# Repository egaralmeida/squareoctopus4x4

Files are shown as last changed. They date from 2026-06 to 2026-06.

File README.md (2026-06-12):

# 4x4 LED Matrix — by @squareoctopus

Wi-Fi controlled 4x4 WS2812B LED matrix running on an ESP32, exposing a simple HTTP JSON API for pixels, effects, and frame sequences.

https://youtube.com/shorts/MrOqMmSNaX8

## Hardware

- **Board:** ESP32-C3 Super Mini (select **ESP32C3 Dev Module** in the boards list) — this is the board the default case is designed for
- **LEDs:** WS2812B strip/matrix, 17 LEDs total, data on **GPIO 4**
- **Layout:** serpentine (zig-zag) rows, 4 wide × 4 tall

### Why LED 0 is ignored

The strip has **17** LEDs but only **16** are visible. LED 0 is a *sacrificial level shifter*: WS2812B data nominally needs 5 V logic, but the ESP32 outputs 3.3 V. The first LED sits close to the ESP32 and (powered appropriately) still reads the 3.3 V signal, then **regenerates the data line at full logic level** for the rest of the strip. It is kept permanently black and is invisible to the API — coordinates `(0,0)`–`(3,3)` map to physical LEDs 1–16.

## Deploying

### Requirements

- [Arduino IDE](https://www.arduino.cc/en/software) or [arduino-cli](https://arduino.github.io/arduino-cli/)
- **ESP32 board support** (Boards Manager: `esp32` by Espressif)
- Libraries (Library Manager):
  - **FastLED**
  - **ArduinoJson**
  - (`WiFi`, `WebServer`, `DNSServer`, `ESPmDNS`, `Preferences` ship with the ESP32 core)

### Flash

Arduino IDE: open `4x4.ino`, select your ESP32 board and port, Upload.

arduino-cli:

```sh
arduino-cli compile --fqbn esp32:esp32:esp32c3 .
arduino-cli upload --fqbn esp32:esp32:esp32c3 -p COM5 .   # adjust port
```

## First-time Wi-Fi setup

The device stores Wi-Fi credentials in flash (NVS). On boot:

1. If credentials are stored, it tries to connect for ~20 seconds.
2. If there are no credentials, or the connection fails, it starts its own access point.

To provision:

1. Connect your phone/laptop to the open Wi-Fi network **`squareoctopus-4x4`**.
2. A captive portal should open automatically (otherwise browse to `http://192.168.4.1`).
3. Pick your network from the list (or type the SSID), enter the password, hit **Connect**.
4. The device reboots and joins your network.

### Finding the device

- **mDNS:** the device is reachable at **`http://squareoctopus-4x4.local`** — no IP needed (works out of the box on macOS, iOS, Android and most Linux distros; on Windows it works on recent versions or with Bonjour installed).
- **Router:** it appears as `squareoctopus-4x4` in your router's DHCP client list.
- **Serial monitor** (115200 baud): the IP is printed on boot.

### Status bar (middle row of the matrix)

| Display | Meaning |
|---|---|
| 🔵 Blue sweeping bar | Searching for / connecting to Wi-Fi |
| 🔴 Red blinking bar | Stored network not found / connection failed |
| 🟠 Orange pulsing bar | Setup (AP) mode — connect to `squareoctopus-4x4` |

The status bar follows the configured `rotation`.

To re-provision (e.g. new router), `POST /wifi/reset` — or just take the device out of range and it will fall back to AP mode after the timeout.

## API reference

All endpoints accept/return JSON. Base URL: `http://squareoctopus-4x4.local` (or `http://<device-ip>`).

Coordinates: `x` = column (0–3, left→right), `y` = row (0–3, top→bottom), at rotation 0. The `rotation` setting rotates the whole logical coordinate space.

Every successful call returns the current device state:

```json
{
  "ok": true,
  "power": true,
  "brightness": 96,
  "rotation": 0,
  "mode": "idle",
  "effect":   { "running": false, "name": "none", "durationMs": 1000, "repeat": 1, "cyclesCompleted": 0 },
  "sequence": { "loaded": false, "running": false, "frameCount": 0, "currentFrame": 0, "repeat": 1, "cyclesCompleted": 0 }
}
```

Errors return `{"ok": false, "error": "<message>"}` with an HTTP 4xx code.

### `GET /state`

Returns the state object above.

### `POST /state`

Set global options. All fields optional; any combination works.

```json
{
  "power": true,
  "brightness": 128,
  "rotation": 90,
  "stop": true,
  "clear": true
}
```

| Field | Type | Notes |
|---|---|---|
| `power` | bool | `false` stops playback and blanks the matrix |
| `brightness` | int 0–255 | Global brightness |
| `rotation` | int | One of `0`, `90`, `180`, `270` (degrees, clockwise). **Persisted across reboots.** |
| `stop` | bool | Stop any running effect/sequence, keep pixels |
| `clear` | bool | Blank the matrix |

### `POST /pixels`

Set individual pixels (manual mode). Stops any running playback.

```json
{
  "clearFirst": true,
  "show": true,
  "pixels": [
    { "x": 0, "y": 0, "r": 255, "g": 0, "b": 0 },
    { "x": 3, "y": 3, "r": 0, "g": 0, "b": 255 }
  ]
}
```

| Field | Type | Default | Notes |
|---|---|---|---|
| `pixels` | array | required | Each needs `x`, `y`, `r`, `g`, `b` |
| `clearFirst` | bool | `false` | Blank before applying |
| `show` | bool | `true` | `false` buffers without displaying |

### `POST /effect`

Run a built-in effect.

```json
{ "name": "plasma", "durationMs": 5000, "repeat": 0 }
```

| Field | Type | Default | Notes |
|---|---|---|---|
| `name` | string | required | One of `rainbowFade`, `breatheWhite`, `cometTrail`, `plasma`, `colorWipeRows` |
| `durationMs` | int | `5000` | Duration of one cycle |
| `repeat` | int | `1` | Number of cycles; `0` = run forever |

### `POST /sequence`

Upload and play a frame-by-frame animation. Limits: **64 frames**, **16 pixels per frame**.

```json
{
  "repeat": 0,
  "frames": [
    {
      "durationMs": 200,
      "clearFirst": true,
      "clearAfter": false,
      "pixels": [ { "x": 1, "y": 1, "r": 0, "g": 255, "b": 0 } ]
    },
    {
      "durationMs": 200,
      "pixels": [ { "x": 2, "y": 2, "r": 0, "g": 255, "b": 0 } ]
    }
  ]
}
```

| Frame field | Type | Default | Notes |
|---|---|---|---|
| `durationMs` | int | `100` | How long the frame stays on screen |
| `clearFirst` | bool | `true` | Blank before drawing the frame |
| `clearAfter` | bool | `false` | Blank after the frame's duration |
| `pixels` | array | required | Same pixel format as `/pixels` |

`repeat` (top level, default `1`): full sequence loops; `0` = endless.

### `POST /wifi/reset`

Clears the stored Wi-Fi credentials and reboots into setup (AP) mode. No body required.

```sh
curl -X POST http://squareoctopus-4x4.local/wifi/reset
```

---

made with care by **@squareoctopus**

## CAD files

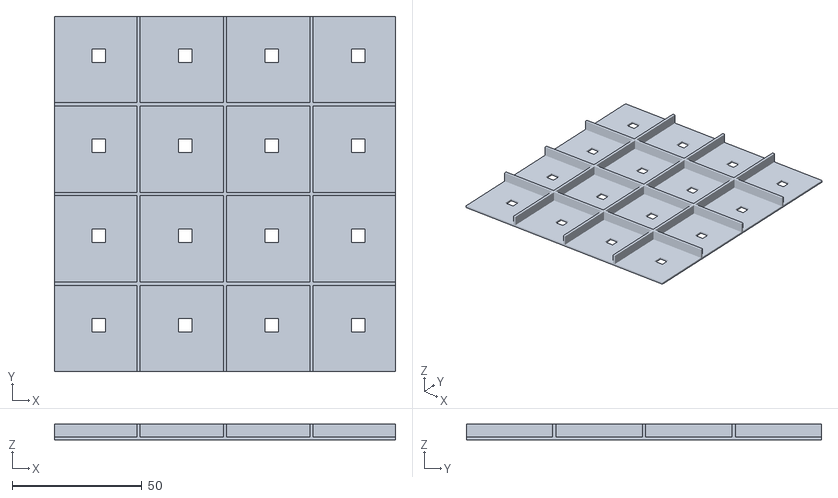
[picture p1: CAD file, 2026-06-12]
LED_support.stl
131.5 x 136.7 x 6.00

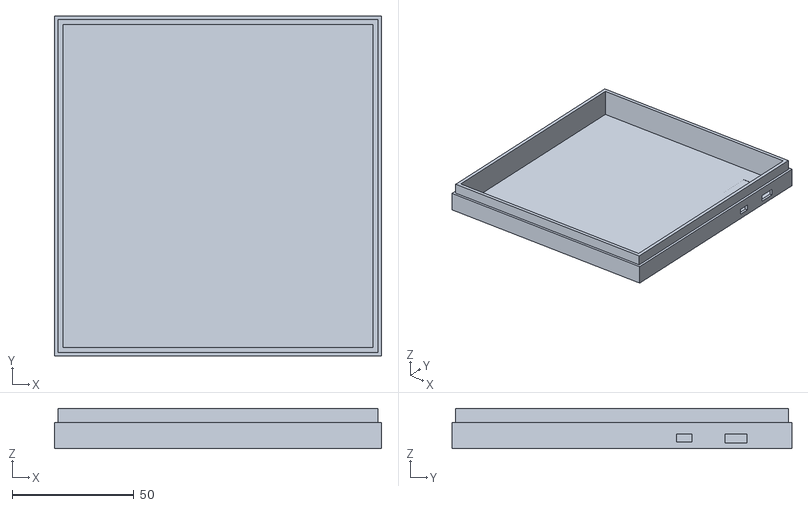
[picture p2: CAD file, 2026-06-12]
back_lid.stl
134.5 x 139.7 x 16.5

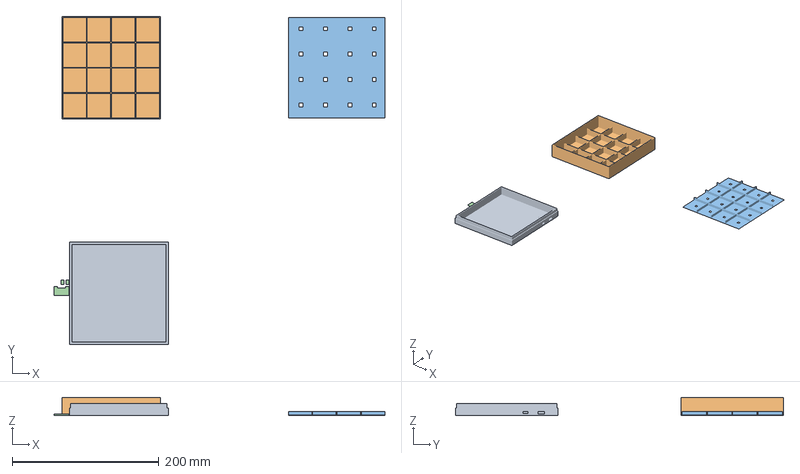
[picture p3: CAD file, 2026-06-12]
squareoctopus4x4.3mf
450.8 x 446.9 x 25.0 mm
back_lid.stl
front.stl
LED_support.stl
esp32_clamps.stl

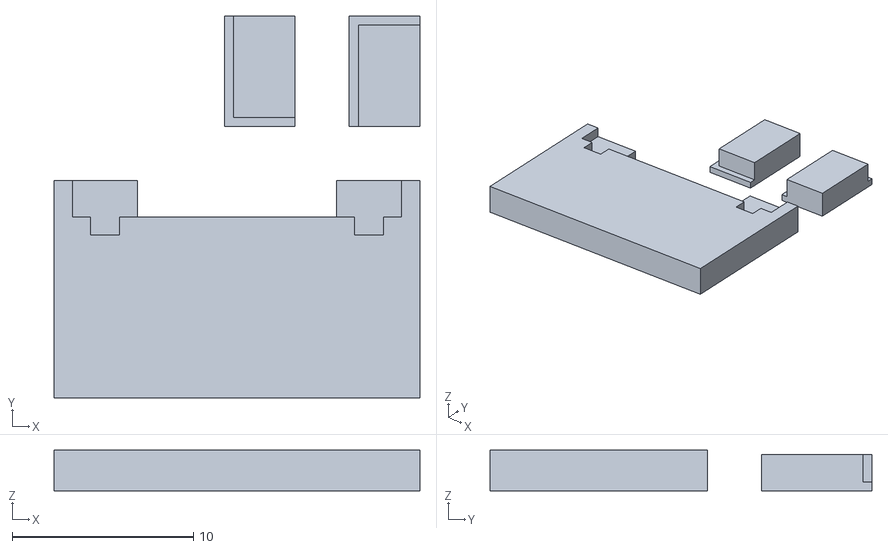
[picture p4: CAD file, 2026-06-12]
esp32_clamps.stl
20.2 x 21.1 x 2.25

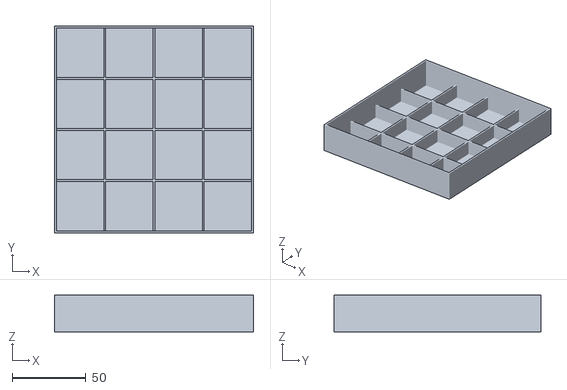
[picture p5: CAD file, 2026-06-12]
front.stl
134.5 x 139.7 x 25.0

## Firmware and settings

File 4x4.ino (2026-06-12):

#include <WiFi.h>
#include <WebServer.h>
#include <DNSServer.h>
#include <ESPmDNS.h>
#include <Preferences.h>
#include <ArduinoJson.h>
#include <FastLED.h>

// ============================
// Wi-Fi provisioning
// ============================
#define AP_SSID            "squareoctopus-4x4"
#define HOSTNAME           "squareoctopus-4x4"
#define WIFI_CONNECT_TIMEOUT_MS 20000
#define NVS_NAMESPACE      "4x4"

Preferences prefs;
DNSServer dnsServer;
bool apMode = false;

// ============================
// LED configuration
// ============================
#define DATA_PIN     4
#define WIDTH        4
#define HEIGHT       4
#define VISIBLE_LEDS (WIDTH * HEIGHT)
#define NUM_LEDS     (VISIBLE_LEDS + 1)   // LED 0 is intentionally ignored
#define LED_TYPE     WS2812B
#define COLOR_ORDER  GRB
#define DEFAULT_BRIGHTNESS 96

CRGB leds[NUM_LEDS];

// ============================
// Server
// ============================
WebServer server(80);

// ============================
// Limits for uploaded sequences
// ============================
static const uint8_t MAX_SEQUENCE_FRAMES = 64;
static const uint8_t MAX_PIXELS_PER_FRAME = 16;

// ============================
// Types
// ============================
enum Mode : uint8_t {
  MODE_OFF = 0,
  MODE_IDLE,
  MODE_MANUAL,
  MODE_EFFECT,
  MODE_SEQUENCE
};

enum EffectType : uint8_t {
  EFFECT_NONE = 0,
  EFFECT_RAINBOW_FADE,
  EFFECT_BREATHE_WHITE,
  EFFECT_COMET_TRAIL,
  EFFECT_PLASMA,
  EFFECT_COLOR_WIPE_ROWS
};

struct PixelUpdate {
  uint8_t x;
  uint8_t y;
  uint8_t r;
  uint8_t g;
  uint8_t b;
};

struct SequenceFrame {
  uint16_t durationMs = 100;
  bool clearFirst = true;
  bool clearAfter = false;
  uint8_t pixelCount = 0;
  PixelUpdate pixels[MAX_PIXELS_PER_FRAME];
};

struct SequenceState {
  bool loaded = false;
  bool running = false;
  uint8_t frameCount = 0;
  uint8_t currentFrame = 0;
  uint32_t repeat = 1;          // 0 = endless
  uint32_t cyclesCompleted = 0;
  uint32_t frameStartedAt = 0;
  SequenceFrame frames[MAX_SEQUENCE_FRAMES];
};

struct EffectState {
  EffectType type = EFFECT_NONE;
  bool running = false;
  uint16_t durationMs = 1000;   // one cycle duration
  uint32_t repeat = 1;          // 0 = endless
  uint32_t cyclesCompleted = 0;
  uint32_t cycleStartedAt = 0;
  uint8_t hue = 0;              // used by comet trail
};

struct DeviceState {
  Mode mode = MODE_IDLE;
  bool power = true;
  uint8_t brightness = DEFAULT_BRIGHTNESS;
  uint16_t rotation = 0; // 0, 90, 180, 270 degrees
} deviceState;

SequenceState sequenceState;
EffectState effectState;

// Used by manual mode / pixels endpoint
bool dirtyShow = false;

// ============================
// Forward declarations
// ============================
uint16_t XY(uint8_t x, uint8_t y);
void showNow();
void clearMatrix(bool show);
void stopAllPlayback(bool keepPixels);
void startEffect(EffectType type, uint16_t durationMs, uint32_t repeat);
void startSequence(uint32_t repeat);
void tickPlayback();
void tickEffect(uint32_t now);
void tickSequence(uint32_t now);
void renderEffectFrame(EffectType type, uint32_t elapsedInCycle);
void handleNotFound();
void handleGetState();
void handlePostState();
void handlePostPixels();
void handlePostEffect();
void handlePostSequence();
bool parseJsonBody(JsonDocument& doc);
void sendJsonError(int code, const char* message);
void sendJsonOk(const String& payload);
const char* modeName(Mode mode);
const char* effectName(EffectType effect);
EffectType parseEffectName(const char* name);
void handlePostWifiReset();
void drawStatusBar(uint8_t progress, CRGB color);
void showNoWifiFeedback();
void tickAPModeFeedback();
bool connectToWiFi();
void startAPMode();
void startApiServer();
void handlePortalRoot();
void handlePortalSave();
void handlePortalRedirect();

// ============================
// XY mapper
// Visible matrix maps to LED 1..16
// LED 0 is ignored on purpose
// Applies the configured rotation before the serpentine mapping
// ============================
uint16_t XY(uint8_t x, uint8_t y) {
  if (x >= WIDTH || y >= HEIGHT) return 0;

  uint8_t rx = x, ry = y;
  switch (deviceState.rotation) {
    case 90:
      rx = HEIGHT - 1 - y;
      ry = x;
      break;
    case 180:
      rx = WIDTH - 1 - x;
      ry = HEIGHT - 1 - y;
      break;
    case 270:
      rx = y;
      ry = WIDTH - 1 - x;
      break;
    default:
      break;
  }
  x = rx;
  y = ry;

  uint16_t physicalIndex;
  if ((y % 2) == 0) {
    physicalIndex = y * WIDTH + x;
  } else {
    physicalIndex = y * WIDTH + (WIDTH - 1 - x);
  }

  return physicalIndex + 1; // +1 because LED 0 is the ignored hack LED
}

// ============================
// Helpers
// ============================
void showNow() {
  if (!deviceState.power) {
    fill_solid(leds, NUM_LEDS, CRGB::Black);
  }
  FastLED.show();
}

void clearMatrix(bool show) {
  fill_solid(leds, NUM_LEDS, CRGB::Black);
  leds[0] = CRGB::Black; // ignored adapter LED stays black too
  if (show) showNow();
}

void stopAllPlayback(bool keepPixels) {
  effectState.running = false;
  effectState.type = EFFECT_NONE;
  effectState.cyclesCompleted = 0;

  sequenceState.running = false;
  sequenceState.currentFrame = 0;
  sequenceState.cyclesCompleted = 0;

  if (!keepPixels) {
    clearMatrix(true);
  }
}

const char* modeName(Mode mode) {
  switch (mode) {
    case MODE_OFF: return "off";
    case MODE_IDLE: return "idle";
    case MODE_MANUAL: return "manual";
    case MODE_EFFECT: return "effect";
    case MODE_SEQUENCE: return "sequence";
    default: return "unknown";
  }
}

const char* effectName(EffectType effect) {
  switch (effect) {
    case EFFECT_RAINBOW_FADE: return "rainbowFade";
    case EFFECT_BREATHE_WHITE: return "breatheWhite";
    case EFFECT_COMET_TRAIL: return "cometTrail";
    case EFFECT_PLASMA: return "plasma";
    case EFFECT_COLOR_WIPE_ROWS: return "colorWipeRows";
    default: return "none";
  }
}

EffectType parseEffectName(const char* name) {
  if (!name) return EFFECT_NONE;
  if (strcmp(name, "rainbowFade") == 0) return EFFECT_RAINBOW_FADE;
  if (strcmp(name, "breatheWhite") == 0) return EFFECT_BREATHE_WHITE;
  if (strcmp(name, "cometTrail") == 0) return EFFECT_COMET_TRAIL;
  if (strcmp(name, "plasma") == 0) return EFFECT_PLASMA;
  if (strcmp(name, "colorWipeRows") == 0) return EFFECT_COLOR_WIPE_ROWS;
  return EFFECT_NONE;
}

bool parseJsonBody(JsonDocument& doc) {
  if (!server.hasArg("plain")) return false;
  String body = server.arg("plain");
  DeserializationError err = deserializeJson(doc, body);
  return !err;
}

void sendJsonError(int code, const char* message) {
  StaticJsonDocument<128> doc;
  doc["ok"] = false;
  doc["error"] = message;
  String out;
  serializeJson(doc, out);
  server.send(code, "application/json", out);
}

void sendJsonOk(const String& payload) {
  server.send(200, "application/json", payload);
}

// ============================
// Status feedback
// Horizontal bar on the middle row, drawn through XY()
// so it honors the configured rotation.
// ============================
void drawStatusBar(uint8_t progress, CRGB color) {
  if (progress > WIDTH) progress = WIDTH;
  fill_solid(leds, NUM_LEDS, CRGB::Black);
  for (uint8_t x = 0; x < progress; x++) {
    leds[XY(x, 1)] = color;
  }
  FastLED.show();
}

void showNoWifiFeedback() {
  // Full red bar blinking for ~2 seconds
  for (uint8_t i = 0; i < 4; i++) {
    drawStatusBar(WIDTH, CRGB::Red);
    delay(250);
    drawStatusBar(0, CRGB::Black);
    delay(250);
  }
}

void tickAPModeFeedback() {
  static uint32_t lastFrame = 0;
  uint32_t now = millis();
  if (now - lastFrame < 33) return;
  lastFrame = now;

  // Slowly pulsing orange bar
  uint8_t v = beatsin8(12, 30, 255);
  fill_solid(leds, NUM_LEDS, CRGB::Black);
  for (uint8_t x = 0; x < WIDTH; x++) {
    leds[XY(x, 1)] = CHSV(28, 255, v);
  }
  FastLED.show();
}

// ============================
// Effect engine
// ============================
void startEffect(EffectType type, uint16_t durationMs, uint32_t repeat) {
  stopAllPlayback(true);

  effectState.type = type;
  effectState.running = true;
  effectState.durationMs = max<uint16_t>(durationMs, 1);
  effectState.repeat = repeat;
  effectState.cyclesCompleted = 0;
  effectState.cycleStartedAt = millis();
  effectState.hue = 0;

  deviceState.mode = MODE_EFFECT;
  deviceState.power = true;
}

void renderEffectFrame(EffectType type, uint32_t elapsedInCycle) {
  uint8_t t8 = millis() / 8;
  uint16_t t16 = millis() / 4;

  switch (type) {
    case EFFECT_RAINBOW_FADE:
      for (uint8_t y = 0; y < HEIGHT; y++) {
        for (uint8_t x = 0; x < WIDTH; x++) {
          uint8_t hue = t8 + x * 16 + y * 24;
          uint8_t val = 180 + sin8((millis() / 4) + x * 32 + y * 40) / 3;
          leds[XY(x, y)] = CHSV(hue, 255, val);
        }
      }
      showNow();
      break;

    case EFFECT_BREATHE_WHITE: {
      uint8_t breath = beatsin8(18, 20, 255);
      for (uint16_t i = 1; i < NUM_LEDS; i++) {
        leds[i] = CRGB(breath, breath, breath);
      }
      showNow();
      break;
    }

    case EFFECT_COMET_TRAIL: {
      fadeToBlackBy(leds + 1, VISIBLE_LEDS, 40);
      uint8_t pos = ((elapsedInCycle / 90) % VISIBLE_LEDS) + 1;
      leds[pos] += CHSV(effectState.hue, 255, 255);

      uint8_t side = ((pos - 1 + 1) % VISIBLE_LEDS) + 1;
      leds[side] += CHSV(effectState.hue + 32, 180, 120);

      effectState.hue++;
      showNow();
      break;
    }

    case EFFECT_PLASMA:
      for (uint8_t y = 0; y < HEIGHT; y++) {
        for (uint8_t x = 0; x < WIDTH; x++) {
          uint8_t v1 = sin8(x * 40 + t16);
          uint8_t v2 = cos8(y * 50 - t16 / 2);
          uint8_t hue = ((uint16_t)v1 + (uint16_t)v2) / 2 + t16 / 8;
          uint8_t val = 120 + (((uint16_t)v1 + (uint16_t)v2) / 4);
          leds[XY(x, y)] = CHSV(hue, 220, val);
        }
      }
      showNow();
      break;

    case EFFECT_COLOR_WIPE_ROWS: {
      uint32_t totalSteps = WIDTH * HEIGHT;
      uint32_t stepDuration = max<uint32_t>(effectState.durationMs / totalSteps, 1);
      uint32_t step = min<uint32_t>(elapsedInCycle / stepDuration, totalSteps);

      clearMatrix(false);
      for (uint8_t y = 0; y < HEIGHT; y++) {
        CRGB c = CHSV(y * 64, 255, 255);
        for (uint8_t x = 0; x < WIDTH; x++) {
          uint32_t idx = y * WIDTH + x;
          if (idx < step) {
            leds[XY(x, y)] = c;
          }
        }
      }
      showNow();
      break;
    }

    default:
      break;
  }
}

void tickEffect(uint32_t now) {
  if (!effectState.running || deviceState.mode != MODE_EFFECT || !deviceState.power) return;

  uint32_t elapsed = now - effectState.cycleStartedAt;

  if (elapsed >= effectState.durationMs) {
    effectState.cyclesCompleted++;

    if (effectState.repeat != 0 && effectState.cyclesCompleted >= effectState.repeat) {
      effectState.running = false;
      effectState.type = EFFECT_NONE;
      deviceState.mode = MODE_IDLE;
      return;
    }

    effectState.cycleStartedAt = now;
    elapsed = 0;

    if (effectState.type == EFFECT_COMET_TRAIL) {
      clearMatrix(false);
    }
  }

  renderEffectFrame(effectState.type, elapsed);
}

// ============================
// Sequence engine
// ============================
void startSequence(uint32_t repeat) {
  stopAllPlayback(true);

  sequenceState.repeat = repeat;
  sequenceState.running = true;
  sequenceState.currentFrame = 0;
  sequenceState.cyclesCompleted = 0;
  sequenceState.frameStartedAt = 0;

  deviceState.mode = MODE_SEQUENCE;
  deviceState.power = true;
}

void tickSequence(uint32_t now) {
  if (!sequenceState.running || deviceState.mode != MODE_SEQUENCE || !deviceState.power) return;
  if (!sequenceState.loaded || sequenceState.frameCount == 0) return;

  if (sequenceState.frameStartedAt == 0) {
    sequenceState.currentFrame = 0;
    SequenceFrame& frame = sequenceState.frames[sequenceState.currentFrame];

    if (frame.clearFirst) {
      clearMatrix(false);
    }

    for (uint8_t i = 0; i < frame.pixelCount; i++) {
      PixelUpdate& p = frame.pixels[i];
      if (p.x < WIDTH && p.y < HEIGHT) {
        leds[XY(p.x, p.y)] = CRGB(p.r, p.g, p.b);
      }
    }
    showNow();
    sequenceState.frameStartedAt = now;
    return;
  }

  SequenceFrame& current = sequenceState.frames[sequenceState.currentFrame];
  if ((now - sequenceState.frameStartedAt) < current.durationMs) return;

  if (current.clearAfter) {
    clearMatrix(true);
  }

  sequenceState.currentFrame++;

  if (sequenceState.currentFrame >= sequenceState.frameCount) {
    sequenceState.cyclesCompleted++;

    if (sequenceState.repeat != 0 && sequenceState.cyclesCompleted >= sequenceState.repeat) {
      sequenceState.running = false;
      deviceState.mode = MODE_IDLE;
      return;
    }

    sequenceState.currentFrame = 0;
  }

  SequenceFrame& next = sequenceState.frames[sequenceState.currentFrame];

  if (next.clearFirst) {
    clearMatrix(false);
  }

  for (uint8_t i = 0; i < next.pixelCount; i++) {
    PixelUpdate& p = next.pixels[i];
    if (p.x < WIDTH && p.y < HEIGHT) {
      leds[XY(p.x, p.y)] = CRGB(p.r, p.g, p.b);
    }
  }

  showNow();
  sequenceState.frameStartedAt = now;
}

void tickPlayback() {
  uint32_t now = millis();

  if (!deviceState.power) return;

  switch (deviceState.mode) {
    case MODE_EFFECT:
      tickEffect(now);
      break;
    case MODE_SEQUENCE:
      tickSequence(now);
      break;
    case MODE_MANUAL:
    case MODE_IDLE:
    case MODE_OFF:
    default:
      if (dirtyShow) {
        showNow();
        dirtyShow = false;
      }
      break;
  }
}

// ============================
// HTTP handlers
// ============================
void handleGetState() {
  StaticJsonDocument<768> doc;
  doc["ok"] = true;
  doc["power"] = deviceState.power;
  doc["brightness"] = deviceState.brightness;
  doc["rotation"] = deviceState.rotation;
  doc["mode"] = modeName(deviceState.mode);

  JsonObject effect = doc.createNestedObject("effect");
  effect["running"] = effectState.running;
  effect["name"] = effectName(effectState.type);
  effect["durationMs"] = effectState.durationMs;
  effect["repeat"] = effectState.repeat;
  effect["cyclesCompleted"] = effectState.cyclesCompleted;

  JsonObject sequence = doc.createNestedObject("sequence");
  sequence["loaded"] = sequenceState.loaded;
  sequence["running"] = sequenceState.running;
  sequence["frameCount"] = sequenceState.frameCount;
  sequence["currentFrame"] = sequenceState.currentFrame;
  sequence["repeat"] = sequenceState.repeat;
  sequence["cyclesCompleted"] = sequenceState.cyclesCompleted;

  String out;
  serializeJson(doc, out);
  sendJsonOk(out);
}

void handlePostState() {
  StaticJsonDocument<512> doc;
  if (!parseJsonBody(doc)) {
    sendJsonError(400, "Invalid or missing JSON body");
    return;
  }

  if (doc["brightness"].is<int>()) {
    int b = doc["brightness"].as<int>();
    if (b < 0 || b > 255) {
      sendJsonError(400, "brightness must be 0..255");
      return;
    }
    deviceState.brightness = (uint8_t)b;
    FastLED.setBrightness(deviceState.brightness);
    dirtyShow = true;
  }

  if (doc["rotation"].is<int>()) {
    int rot = doc["rotation"].as<int>();
    if (rot != 0 && rot != 90 && rot != 180 && rot != 270) {
      sendJsonError(400, "rotation must be 0, 90, 180 or 270");
      return;
    }
    deviceState.rotation = (uint16_t)rot;
    prefs.putUShort("rot", deviceState.rotation);
    dirtyShow = true;
  }

  if (doc["stop"].is<bool>() && doc["stop"].as<bool>()) {
    stopAllPlayback(true);
    if (deviceState.power) {
      deviceState.mode = MODE_IDLE;
    }
  }

  if (doc["clear"].is<bool>() && doc["clear"].as<bool>()) {
    clearMatrix(true);
    if (deviceState.power) {
      deviceState.mode = MODE_IDLE;
    }
  }

  if (doc["power"].is<bool>()) {
    bool p = doc["power"].as<bool>();
    deviceState.power = p;

    if (!p) {
      stopAllPlayback(false);
      deviceState.mode = MODE_OFF;
    } else {
      if (deviceState.mode == MODE_OFF) {
        deviceState.mode = MODE_IDLE;
      }
      dirtyShow = true;
    }
  }

  handleGetState();
}

void handlePostPixels() {
  StaticJsonDocument<2048> doc;
  if (!parseJsonBody(doc)) {
    sendJsonError(400, "Invalid or missing JSON body");
    return;
  }

  JsonArray pixels = doc["pixels"].as<JsonArray>();
  if (pixels.isNull()) {
    sendJsonError(400, "pixels array is required");
    return;
  }

  bool clearFirst = doc["clearFirst"] | false;
  bool show = doc["show"] | true;

  stopAllPlayback(true);

  if (!deviceState.power) {
    deviceState.power = true;
  }

  if (clearFirst) {
    clearMatrix(false);
  }

  for (JsonObject p : pixels) {
    if (!p["x"].is<int>() || !p["y"].is<int>() ||
        !p["r"].is<int>() || !p["g"].is<int>() || !p["b"].is<int>()) {
      sendJsonError(400, "each pixel needs x,y,r,g,b");
      return;
    }

    int x = p["x"].as<int>();
    int y = p["y"].as<int>();
    int r = p["r"].as<int>();
    int g = p["g"].as<int>();
    int b = p["b"].as<int>();

    if (x < 0 || x >= WIDTH || y < 0 || y >= HEIGHT) {
      sendJsonError(400, "pixel coordinate out of range");
      return;
    }
    if (r < 0 || r > 255 || g < 0 || g > 255 || b < 0 || b > 255) {
      sendJsonError(400, "r,g,b must be 0..255");
      return;
    }

    leds[XY((uint8_t)x, (uint8_t)y)] = CRGB((uint8_t)r, (uint8_t)g, (uint8_t)b);
  }

  deviceState.mode = MODE_MANUAL;
  if (show) {
    showNow();
  } else {
    dirtyShow = true;
  }

  handleGetState();
}

void handlePostEffect() {
  StaticJsonDocument<512> doc;
  if (!parseJsonBody(doc)) {
    sendJsonError(400, "Invalid or missing JSON body");
    return;
  }

  const char* name = doc["name"];
  if (!name) {
    sendJsonError(400, "effect name is required");
    return;
  }

  EffectType type = parseEffectName(name);
  if (type == EFFECT_NONE) {
    sendJsonError(400, "unknown effect");
    return;
  }

  uint16_t durationMs = doc["durationMs"] | 5000;
  uint32_t repeat = doc["repeat"] | 1;

  startEffect(type, durationMs, repeat);
  handleGetState();
}

void handlePostSequence() {
  StaticJsonDocument<12288> doc;
  if (!parseJsonBody(doc)) {
    sendJsonError(400, "Invalid or missing JSON body");
    return;
  }

  JsonArray frames = doc["frames"].as<JsonArray>();
  if (frames.isNull()) {
    sendJsonError(400, "frames array is required");
    return;
  }

  size_t frameCount = frames.size();
  if (frameCount == 0) {
    sendJsonError(400, "frames array cannot be empty");
    return;
  }
  if (frameCount > MAX_SEQUENCE_FRAMES) {
    sendJsonError(400, "too many frames");
    return;
  }

  sequenceState.loaded = false;
  sequenceState.frameCount = 0;

  uint8_t frameIndex = 0;
  for (JsonObject frameObj : frames) {
    if (frameIndex >= MAX_SEQUENCE_FRAMES) break;

    SequenceFrame& frame = sequenceState.frames[frameIndex];
    frame.durationMs = frameObj["durationMs"] | 100;
    frame.clearFirst = frameObj["clearFirst"] | true;
    frame.clearAfter = frameObj["clearAfter"] | false;
    frame.pixelCount = 0;

    JsonArray pixels = frameObj["pixels"].as<JsonArray>();
    if (pixels.isNull()) {
      sendJsonError(400, "each frame needs a pixels array");
      return;
    }
    if (pixels.size() > MAX_PIXELS_PER_FRAME) {
      sendJsonError(400, "too many pixels in a frame");
      return;
    }

    uint8_t pixelIndex = 0;
    for (JsonObject p : pixels) {
      if (!p["x"].is<int>() || !p["y"].is<int>() ||
          !p["r"].is<int>() || !p["g"].is<int>() || !p["b"].is<int>()) {
        sendJsonError(400, "each pixel needs x,y,r,g,b");
        return;
      }

      int x = p["x"].as<int>();
      int y = p["y"].as<int>();
      int r = p["r"].as<int>();
      int g = p["g"].as<int>();
      int b = p["b"].as<int>();

      if (x < 0 || x >= WIDTH || y < 0 || y >= HEIGHT) {
        sendJsonError(400, "pixel coordinate out of range");
        return;
      }
      if (r < 0 || r > 255 || g < 0 || g > 255 || b < 0 || b > 255) {
        sendJsonError(400, "r,g,b must be 0..255");
        return;
      }

      frame.pixels[pixelIndex].x = (uint8_t)x;
      frame.pixels[pixelIndex].y = (uint8_t)y;
      frame.pixels[pixelIndex].r = (uint8_t)r;
      frame.pixels[pixelIndex].g = (uint8_t)g;
      frame.pixels[pixelIndex].b = (uint8_t)b;
      pixelIndex++;
    }

    frame.pixelCount = pixelIndex;
    frameIndex++;
  }

  sequenceState.frameCount = frameIndex;
  sequenceState.loaded = true;

  uint32_t repeat = doc["repeat"] | 1;
  startSequence(repeat);

  handleGetState();
}

void handleNotFound() {
  sendJsonError(404, "Not found");
}

void handlePostWifiReset() {
  prefs.remove("ssid");
  prefs.remove("pass");
  server.send(200, "application/json", "{\"ok\":true,\"message\":\"WiFi credentials cleared, rebooting into setup mode\"}");
  delay(500);
  ESP.restart();
}
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
void loop() {
  if (apMode) {
    dnsServer.processNextRequest();
    server.handleClient();
    tickAPModeFeedback();
    return;
  }

  server.handleClient();
  tickPlayback();
}
